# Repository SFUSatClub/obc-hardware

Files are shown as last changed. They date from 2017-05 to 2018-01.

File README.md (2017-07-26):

# OBC Hardware #

**demoboard_v1:** test board featuring RTC, flash memory, watchdog and SEL protection, to be tested with the TMS570LS0432 Launchpad board.

**OBC_prototypeA:** design for PC104 compliant OBC prototype, including onboard MCU, flash memory, SEL protection and power supplies. Includes all features of demoboard, interfaced to TMS570LS0714 MCU.

**Kicad-Lib:** SFUSat's common footprint and schematic symbol library.

## Getting started: ##
Clone this repo In the obc-hardware directory, run git submodule init In the obc-hardware directory, run git submodule update

Open KiCAD, navigate to the project you're interested in.
In EESchema, go to Preferences > Component Libraries
1. "Add" a user defined search path, select the KiCad-Lib directory in the obc-hardware directory
2. "Add" component library files and select the SFUSat.lib file in the KiCad-Lib folder
3. Press ok.

**Note:** issues may arise when using relative paths. Select absolute paths by choosing "No" when asked if you want to use a relative path

Exit back to the KiCad home window and go to Pcbnew > Preferences > Footprint Libraries Manager > "Project Specific Libraies" tab:

1. "Add Library"
2. Nickname: SFUSat
3. Library Path: ${KIPRJMOD}/KiCad-Lib/SFUSat.pretty

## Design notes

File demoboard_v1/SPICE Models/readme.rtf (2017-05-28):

The SPICE model for the DMN2075U needs to be included as a sub circuit. For copyright reasons, it is not posted to git, but can be downloaded from here:

https://www.diodes.com/products/discrete/mosfets/mosfet-master-table/part/DMN2075U

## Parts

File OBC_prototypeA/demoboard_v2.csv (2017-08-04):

Reference | Value | Footprint | Datasheet
U2 | AP7331 | SFUSat:SOT25
P1 | 3v3_IN_CONNECTOR | SFUSat:2x01In_Header_v2
C2 | 1uF | SFUSat:C_0402
C21 | 1µF | SFUSat:C_0402
U1 | TMS570LS0714 | Housings_QFP:LQFP-144_20x20mm_Pitch0.5mm
C17 | 0.1µF | SFUSat:C_0402
C19 | 0.1µF | SFUSat:C_0402
C20 | 0.1µF | SFUSat:C_0402
C14 | 0.1µF | SFUSat:C_0402
C15 | 0.1µF | SFUSat:C_0402
C16 | 0.1µF | SFUSat:C_0402
C18 | 0.1µF | SFUSat:C_0402
C4 | 0.1µF | SFUSat:C_0402
C5 | 0.1µF | SFUSat:C_0402
C6 | 0.1µF | SFUSat:C_0402
C7 | 0.1µF | SFUSat:C_0402
C9 | 0.1µF | SFUSat:C_0402
C10 | 0.1µF | SFUSat:C_0402
C11 | 0.1µF | SFUSat:C_0402
C12 | 0.1µF | SFUSat:C_0402
C13 | 0.1µF | SFUSat:C_0402
U3 | AP7361_3.3v | SFUSat:SOT-223
C23 | 1µF | SFUSat:C_0402
C22 | 4.7µF | SFUSat:C_0402
U4 | INA301 | SFUSat:VSSOP_8
R1 | 7.5k | SFUSat:R_0402
R3 | 0.04 | Resistors_SMD:R_2512
P2 | INA_INPUT | SFUSat:3x_01In_Header_v2
P3 | INA_GND | SFUSat:3x_01In_Header_v2
P4 | INA_EN | SFUSat:2x01In_Header_v2
Q1 | DMN2075U | SFUSat:SOT23_DMN2075U
R4 | 10k | SFUSat:R_0402
P5 | INA_OUTPUT | SFUSat:2x01In_Header_v2
Q2 | DMN2075U | SFUSat:SOT23_DMN2075U
Q3 | 1v2_GOOD | SFUSat:SOT23_DMN2075U
D1 | LED | SFUSat:LED_0603
R6 | 270 | SFUSat:R_0402
R5 | 10K | SFUSat:R_0402
VR1 | Trimpot | SFUSat:Trimpot_Bourns_TC33
J1 | PC104-8BIT | SFUSat:PC104-8bit
Q4 | DMN2075U | SFUSat:SOT23_DMN2075U
D2 | PESD5Zx | SFUSat:PESD57zx
P6 | USB_PORT | SFUSat:USB_MINIB_SMD
U10 | FT230XQ-R | SFUSat:QFN-16_650P
P11 | USB_5V | SFUSat:2x01In_Header_v2
R2 | 27 | SFUSat:R_0402
R31 | 27 | SFUSat:R_0402
C33 | 10nF | SFUSat:C_0402
C8 | 100nF | SFUSat:C_0402
R32 | 10k | SFUSat:R_0402
R33 | 10k | SFUSat:R_0402
R34 | 10k | SFUSat:R_0402
R35 | 10k | SFUSat:R_0402
R36 | 270 | SFUSat:R_0402
R37 | 270 | SFUSat:R_0402
D4 | TX | SFUSat:LED_0603
D5 | RX | SFUSat:LED_0603
W15 | TEST_1P | SFUSat:Test_Point
Y1 | XTAL | SFUSat:SMD_XTAL
C27 | 33pF | SFUSat:C_0402
C28 | 33pF | SFUSat:C_0402
P7 | OSC_FUALT_INJECT | SFUSat:2x01In_Header_v2
SW2 | SPST | SFUSat:Tact_SW_SMD_v2
W12 | nERROR | SFUSat:Test_Point
C32 | 0.1µF | SFUSat:C_0402
R25 | 10k | SFUSat:R_0402
U9 | TPS3110 | SFUSat:SOT_23_6
C31 | 0.1µF | SFUSat:C_0402
SW1 | SPST | SFUSat:Tact_SW_SMD_v2
R22 | 200k | SFUSat:R_0402
R23 | 187k | SFUSat:R_0402
R24 | 100k | SFUSat:R_0402
W14 | RESET_TEST | SFUSat:Test_Point
R28 | 100k | SFUSat:R_0402
R27 | 100k | SFUSat:R_0402
R29 | 100k | SFUSat:R_0402
R30 | 100k | SFUSat:R_0402
P12 | JTAG_20PIN | SFUSat:JTAG_20pin
JTAG5V_IN1 | JTAG5V_IN | SFUSat:2x01In_Header_v2
P13 | WD_EN | SFUSat:2x01In_Header_v2
R38 | 1k | SFUSat:R_0402
R7 | 10k | SFUSat:R_0402
W7 | AD1EVT1 | SFUSat:Test_Point
W8 | GIOB2 | SFUSat:Test_Point
Q5 | DMN2075U | SFUSat:SOT23_DMN2075U
D3 | LED | SFUSat:LED_0603
R9 | 270 | SFUSat:R_0402
R8 | 10k | SFUSat:R_0402
R26 | 10k | SFUSat:R_0402
W13 | WD_TEST | SFUSat:Test_Point
U5 | FLASH_IS25LP016D | SFUSat:SOT-8_208mil_medium
R11 | 10k | SFUSat:R_0402
C24 | 0.1µF | SFUSat:C_0402
R10 | 10k | SFUSat:R_0402
W1 | TEST_1P | SFUSat:Test_Point
R12 | 0 | SFUSat:R_0402
R13 | 10k | SFUSat:R_0402
W2 | TEST_1P | SFUSat:Test_Point
U6 | FLASH_IS25LP016D | SFUSat:SOT-8_208mil_medium
R15 | 10k | SFUSat:R_0402
C25 | 0.1µF | SFUSat:C_0402
R14 | 10k | SFUSat:R_0402
W3 | TEST_1P | SFUSat:Test_Point
R16 | 0 | SFUSat:R_0402
R17 | 10k | SFUSat:R_0402
W4 | TEST_1P | SFUSat:Test_Point
U7 | FLASH_IS25LP016D | SFUSat:SOT-8_208mil_medium
R19 | 10k | SFUSat:R_0402
C26 | 0.1µF | SFUSat:C_0402
R18 | 10k | SFUSat:R_0402
W5 | TEST_1P | SFUSat:Test_Point
R20 | 0 | SFUSat:R_0402
R21 | 10k | SFUSat:R_0402
W6 | TEST_1P | SFUSat:Test_Point
P10 | FLASH_CS | SFUSat:3x_01In_Header_v2
P9 | FLASH_SPI | SFUSat:3x_01In_Header_v2
U8 | AB-RTCMC-EOA9-S3 | SFUSat:RTC_AB-RTCMC_EA09_S3
C29 | 10nF | SFUSat:C_0402
C30 | 470µF | SFUSat:Supercap_v2
W9 | CLKOUT | SFUSat:Test_Point
W11 | RTC_INT | SFUSat:Test_Point
W10 | RTC_OE | SFUSat:Test_Point
P8 | RTC_SPI | SFUSat:4x01In_Header_v2

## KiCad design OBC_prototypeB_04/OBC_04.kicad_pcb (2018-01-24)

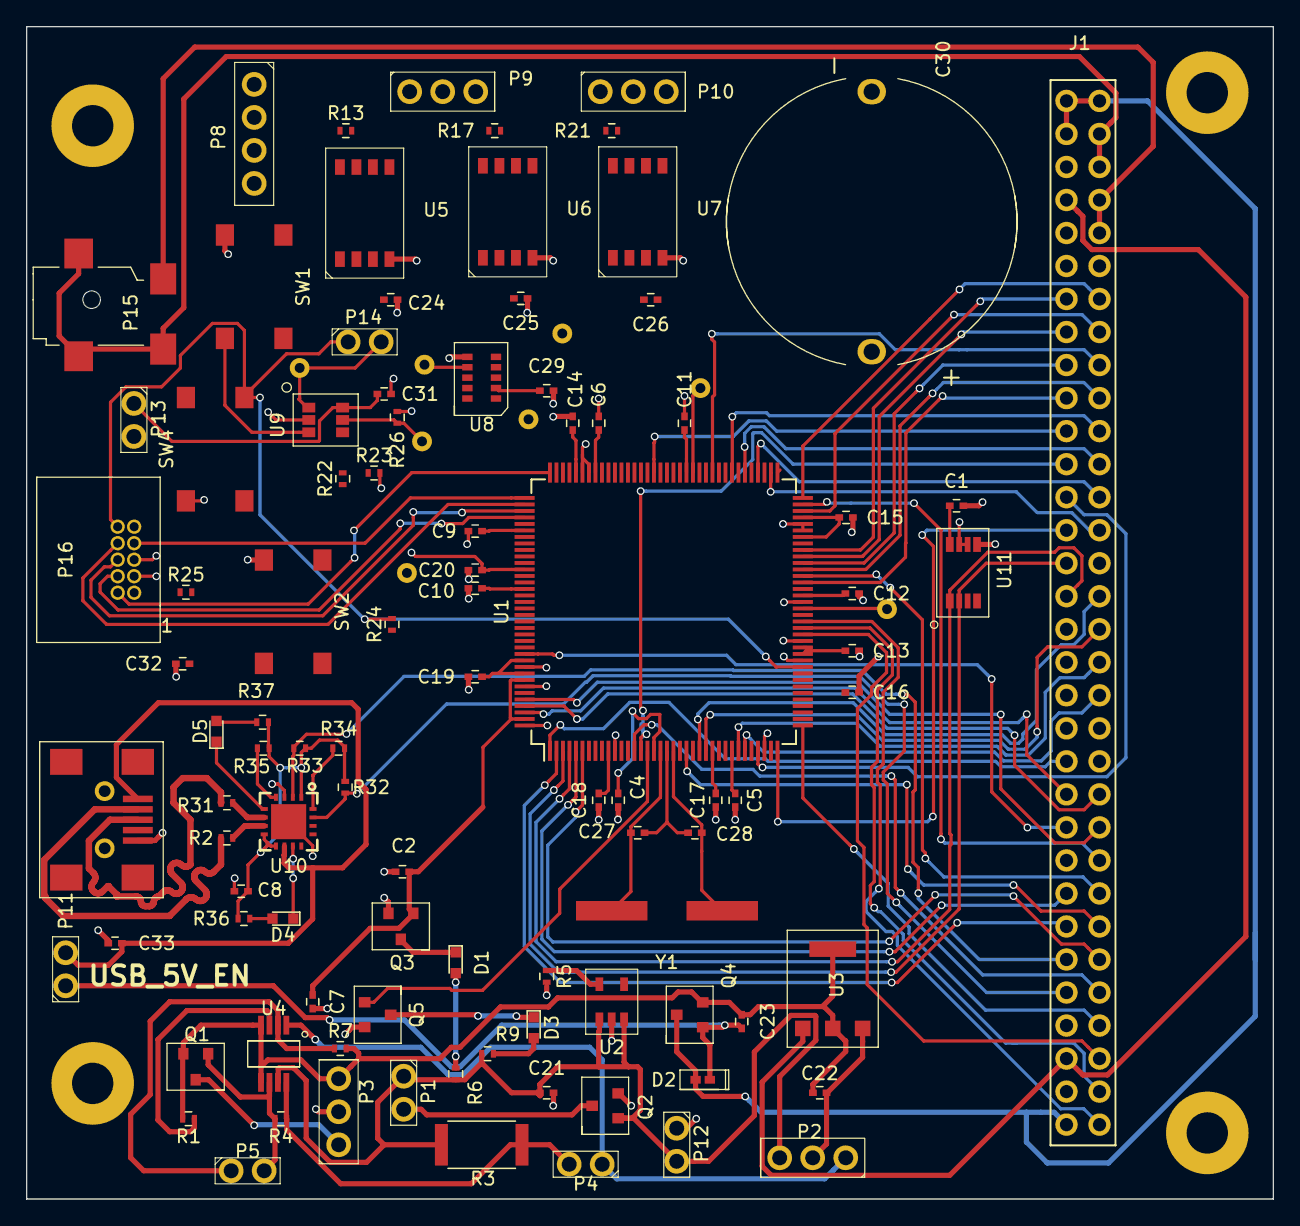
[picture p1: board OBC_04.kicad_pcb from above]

Board: 2 copper layers, 95.9 x 90.2 mm, 104 parts (0 on the bottom side), 107 nets.

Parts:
C1, C4, C5, C6, C7, C9, C10, C11, C12, C13, C14, C15, C16, C17, C18, C19, C20, C24, C25, C26, C31, C32: 0.1µF; C_0402
C2: 10µF; C_0402
C8: 100nF; C_0402
C21, C23: 1µF; C_0402
C22: 4.7µF; C_0402
C27, C28: 33pF; C_0402
C29, C33: 10nF; C_0402
C30: 470µF; Supercap_v2
D1, D3: LED; LED_0603
D2: PESD5Zx; PESD57zx
D4: TX; LED_0603
D5: RX; LED_0603
J1: PC104-8BIT; PC104-8bit
P1: 3v3_IN_CONNECTOR; 2x01In_Header_v2
P2: INA_INPUT; 3x_01In_Header_v2
P3: INA_GND; 3x_01In_Header_v2
P4: INA_EN; 2x01In_Header_v2
P5: INA_OUTPUT; 2x01In_Header_v2
P6: USB_PORT; USB_MINIB_SMD
P8: RTC_SPI; 4x01In_Header_v2
P9: FLASH_SPI; 3x_01In_Header_v2
P10: FLASH_CS; 3x_01In_Header_v2
P11: USB_5V; 2x01In_Header_v2
P12: LOAD; 2x01In_Header_v2
P13: WD_EN; 2x01In_Header_v2
P14: WD_RST_EN; 2x01In_Header_v2
P15: 3pin-DC-power; PJ-028-SMT-TR-3pin-DC-jackPJ-028-SMT-TR
P16: JTAG_10PIN; JTAG_10pin_1.27mm
Q1, Q2, Q4, Q5: DMN2075U; SOT23_DMN2075U
Q3: 1v2_GOOD; SOT23_DMN2075U
R1: 7.5k; R_0402
R2, R31: 27; R_0402
R3: 0.04; R_2512
R4, R7, R13, R17, R21, R25, R26, R32, R33, R34, R35: 10k; R_0402
R5: 10K; R_0402
R6, R9, R36, R37: 270; R_0402
R22: 200k; R_0402
R23: 187k; R_0402
R24: 2.2k; R_0402
SW1, SW2, SW4: SPST; Tact_SW_SMD_v2
U1: TMS570LS0714; LQFP-144_20x20mm_Pitch0.5mm
U2: XC6222B121MR-G; SOT25
U3: AP7361_3.3v; SOT-223
U4: INA301; VSSOP_8
U5, U6, U7: FLASH_IS25LP016D; SOT-8_208mil_medium
U8: AB-RTCMC-EOA9-S3; RTC_AB-RTCMC_EA09_S3
U9: TPS3110; SOT_23_6
U10: FT230XQ-R; QFN-16_650P
U11: STLM75; TSSOP-8-3x3mm-SOT505-1
W7: AD1EVT1; Test_Point
W8: GIOB2; Test_Point
W9: CLKOUT; Test_Point
W10: RTC_OE; Test_Point
W11: RTC_INT; Test_Point
W12: nERROR; Test_Point
W13: WD_TEST; Test_Point
W14: RESET_TEST; Test_Point
Y1: XTAL; SMD_XTAL

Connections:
1v2: C2.1, C4.1, C5.1, C6.1, C7.1, C9.1, C10.1, C11.1, C12.1, C13.1, Q3.2, R5.1, R22.1, U1.17, U1.29, U1.45, U1.48, U1.49, U1.57, U1.87, U1.101, U1.114, U1.123, U1.137, U1.143, U2.5
3v3: C1.1, C14.2, C15.1, C16.1, C17.2, C18.1, C19.1, C20.1, C21.1, C24.2, C25.2, C26.2, C29.1, P1.1, P2.3, P12.2, P13.2, P16.1, Q2.2, R3.2, R6.1, R9.1, R13.1, R17.1, R21.1, R24.1, R25.1, U1.10, U1.26, U1.42, U1.66, U1.69, U1.104, U1.120, U1.134, U1.136, U2.1, U2.3, U4.7, U5.3, U5.8, U6.3, U6.8, U7.3, U7.8, U8.2, U11.8
3v3_OUTPUT: C22.1, P2.2, U3.3
5v0: C23.1, D2.1, J1.3B, J1.29B, P11.1, Q4.2, U3.1
104_GND: C22.2, C23.2, P3.3, Q1.3, Q4.3, R1.2, R7.2, U3.2, U3.4, U4.4, U4.5
104_In_GND: C8.2, C33.2, D2.2, J1.1B, J1.31B, J1.32A, J1.32B, P6.5, Q4.1, U10.3, U10.13, U10.17
/MCU_Support_Reset/OSC_N: C28.2, U1.20, Y1.2
/MCU_Support_Reset/OSC_P: C27.1, U1.18, Y1.1
/PC104_Connector/RUSB_N: R2.1, U10.7
/PC104_Connector/RUSB_P: R31.1, U10.6
AD1_3: J1.19A, U1.74
AD1_4: J1.20A, U1.76
AD1_5: J1.21A, U1.78
AD1_6: J1.22A, U1.80
AD1_7: J1.23A, U1.61
AD1_8: J1.24A, U1.83
AD1_9: J1.25A, U1.70
AD1_10: J1.26A, U1.72
AD1_17: J1.23B, U1.59
AD1_18: J1.24B, U1.62
AD1_19: J1.25B, U1.63
AD1_20: J1.26B, U1.64
ANTENNA_DEPLOY: J1.7A, U1.22
FLASH0_CS: P10.3, U1.105, U5.1
FLASH1_CS: P10.2, U1.130, U6.1
FLASH2_CS: P10.1, U1.40, U7.1
FLASH_CLK: P9.1, U1.95, U5.6, U6.6, U7.6
FLASH_MISO: P9.2, U1.94, U5.2, U6.2, U7.2
FLASH_MOSI: P9.3, U1.93, U5.5, U6.5, U7.5
FTDI_VCCIO: C8.1, R32.1, R33.1, R34.1, R35.1, R36.1, R37.1, U10.1, U10.8, U10.9
GIOA0: J1.7B, U1.2
GIOA1: J1.8B, U1.5
GIOA6: Q5.2, U1.16
GIOB1: J1.10B, U1.133, U8.7, W11.1
GIOB2: J1.11B, U1.142
GIOB3: J1.12B, U1.1
GND: C1.2, C2.2, C4.2, C5.2, C6.2, C7.2, C9.2, C10.2, C11.2, C12.2, C13.2, C14.1, C15.2, C16.2, C17.1, C18.2, C19.2, C20.2, C21.2, C24.1, C25.1, C26.1, C29.2, C30.2, C31.2, C32.2, P3.2, P12.1, P16.3, P16.5, Q2.3, Q3.3, Q5.3, R5.2, R23.2, R26.2, SW1.2, SW2.2, SW4.2, U1.11, U1.21, U1.27, U1.28, U1.34, U1.43, U1.44, U1.47, U1.50, U1.56, U1.67, U1.68, U1.88, U1.102, U1.103, U1.115, U1.121, U1.122, U1.135, U1.138, U1.144, U2.2, U5.4, U6.4, U7.4, U8.6, U9.2, U11.4, U11.5, U11.6, U11.7
I2C_SCL: J1.18B, U1.3, U11.2
I2C_SDA: J1.17B, U1.4, U11.1
INA_ALERT: P5.2, Q1.2, R4.2, U4.6
INA_INPUT: P2.1, P4.1, U4.1
INA_OUT: P5.1, R7.1, U1.73, U4.2
MASTER_RESET: P14.1, P16.10, R24.2, SW4.1, U1.46
NHET1_4: J1.19B, U1.36
NHET1_7: J1.20B, U1.33
NHET1_22: J1.21B, U1.15
NHET1_26: J1.22B, U1.92
unnamed: C27.2, C28.1, U1.19
unnamed: C30.1, U8.9
unnamed: C31.1, P13.1, U9.6
unnamed: C32.1, R25.2, SW2.1, U1.116
unnamed: D1.1, Q3.1
unnamed: D1.2, R6.2
unnamed: D3.1, Q5.1
unnamed: D3.2, R9.2
unnamed: D4.1, U10.11
unnamed: D4.2, R36.2
unnamed: D5.1, U10.5
unnamed: D5.2, R37.2
unnamed: J1.28A, J1.29A, P15.1
unnamed: J1.30A, J1.31A, P15.2, P15.3
unnamed: P1.2, Q2.1
unnamed: P3.1, Q1.1
unnamed: P4.2, R3.1, R4.1, U4.8
unnamed: P14.2, U9.1, W14.1
unnamed: R1.1, U4.3
unnamed: R13.2, U5.7
unnamed: R17.2, U6.7
unnamed: R21.2, U7.7
unnamed: R22.2, R23.1, U9.4
unnamed: R34.2, U10.16
unnamed: R35.2, U10.4
unnamed: SW1.1, U9.3
unnamed: U1.55, W8.1
unnamed: U1.86, W7.1
unnamed: U8.1, W10.1
unnamed: U8.3, W9.1
RF_ADC1: J1.8A, U1.60
RF_ADC2: J1.9A, U1.71
RF_CLK: J1.1A, U1.53
RF_CS: J1.4A, U1.37
RF_GAIN_CS: J1.6A, U1.6
RF_IRQ: J1.5A, U1.14
RF_MISO: J1.3A, U1.51
RF_MOSI: J1.2A, U1.52
RF_PWM1: J1.10A, U1.140
RF_PWM2: J1.11A, U1.141
RTC_CLK: P8.2, U1.100, U8.4
RTC_CS: P8.1, U1.32, U8.8
RTC_MISO: P8.3, U1.98, U8.5
RTC_MOSI: P8.4, U1.99, U8.10
SPI4_CLK: J1.16A, U1.25
SPI4_CS0: J1.17A, U1.24
SPI4_MISO: J1.14A, U1.31
SPI4_MOSI: J1.15A, U1.30
TCK: P16.4, U1.112
TDI: P16.8, U1.110
TDO: P16.6, U1.111
TMS: P16.2, U1.108
UART_RX: J1.5B, R32.2, U1.38, U10.15
UART_TX: J1.6B, R33.2, U1.39, U10.2
USB_5V: C33.1, P6.1, P11.2, U10.10
USB_N: P6.2, R2.2
USB_P: P6.3, R31.2
WATCHDOG: R26.1, U1.126, U9.5, W13.1
nERROR: U1.117, W12.1
nTRST: P16.7, U1.109

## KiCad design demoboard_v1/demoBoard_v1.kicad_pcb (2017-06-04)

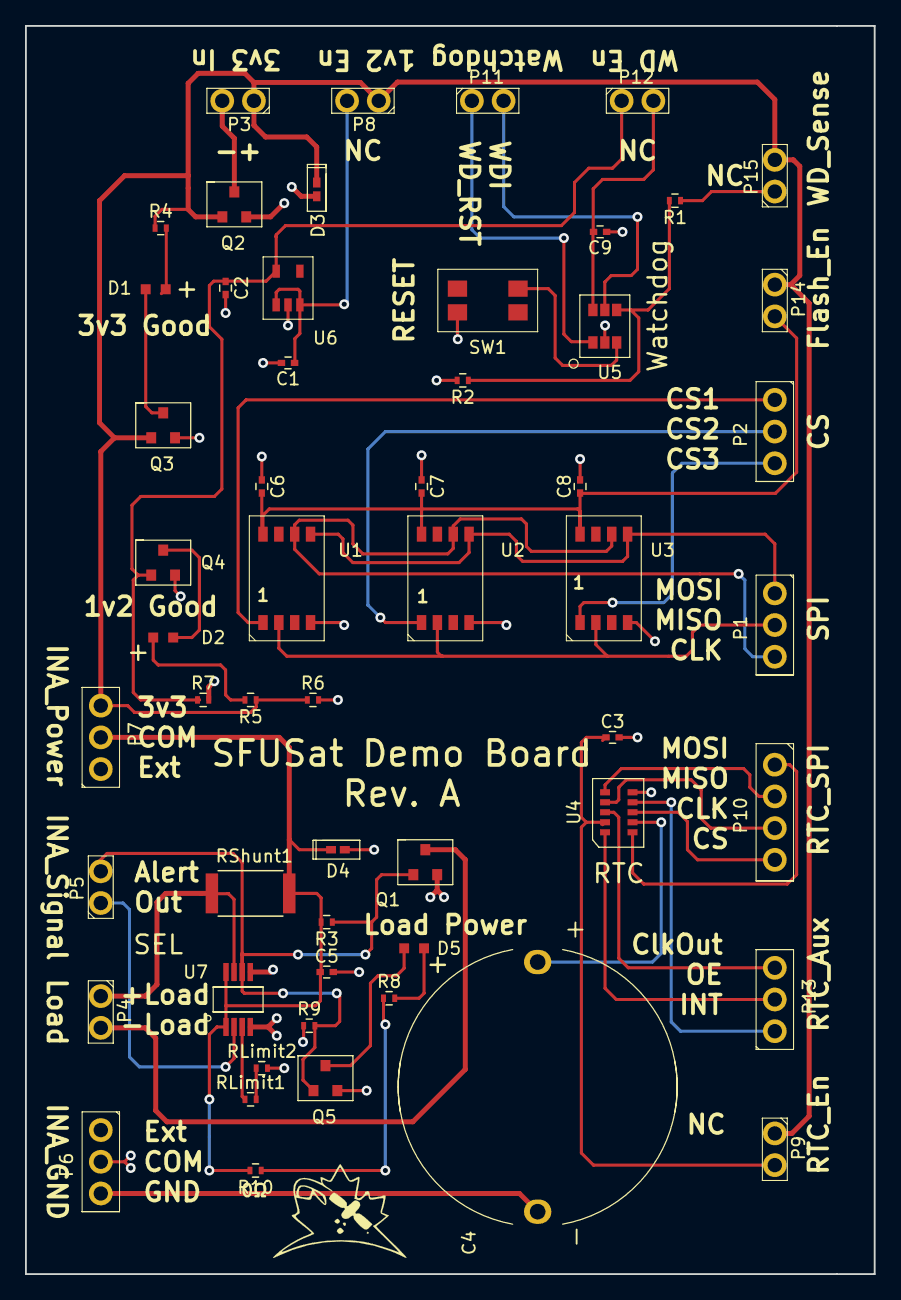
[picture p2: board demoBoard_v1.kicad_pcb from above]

Board: 2 copper layers, 68.0 x 100.0 mm, 55 parts (0 on the bottom side), 42 nets.

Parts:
C1, C2: 1µF; C_0402
C3: 10nF; C_0402
C4: 470µF; Supercap_v2
C5, C6, C7, C8, C9: 0.1µF; C_0402
D1: 3.3V On; LED_150060GS75000
D2: 1.2V On; LED_150060GS75000
D3, D4: PESD5Zx; PESD57zx
D5: Led_Small; LED_150060GS75000
P1: SPI_Header; 3x_01In_Header_v2
P2: 3x_CS_Header; 3x_01In_Header_v2
P3: Power_Header; 2x01In_Header_v2
P4: LOAD; 2x01In_Header_v2
P5: INA_Signal; 2x01In_Header_v2
P6: INA_GND; 3x_01In_Header_v2
P7: INA_Power; 3x_01In_Header_v2
P8: 1.2V_3.3V_NC; 2x01In_Header_v2
P9: RTC_3.3_NC; 2x01In_Header_v2
P10: RTC_Serial; 4x01In_Header_v2
P11: WD_Header; 2x01In_Header_v2
P12: WD_1.2V_NC; 2x01In_Header_v2
P13: RTC_Aux; 3x_01In_Header_v2
P14: Flash_3v3_NC; 2x01In_Header_v2
P15: WD_SENSE_3.3V_NC; 2x01In_Header_v2
Q1, Q2, Q3, Q4, Q5: DMN2075U; SOT23_DMN2075U
R1: 820K; R_0402
R2: 180K; R_0402
R3, R6, R7: 10K; R_0402
R4, R5, R8: 39; R_0402
R9: 10k; R_0402
R10: 0; R_0402
RLimit1: 8870; R_0402
RLimit2: 130; R_0402
RShunt1: 0.06; R_2512
SW1: Tact_Switch_NO; Tact_SW_SMD
U1, U2, U3: S25FL164K0XMFV010; SOT-8_208mil_medium
U4: AB-RTCMC-EOA9-S3; RTC_AB-RTCMC_EA09_S3
U5: TPS3110; SOT_23_6
U6: AP7331; SOT25
U7: INA301; VSSOP_8

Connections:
+1V2: C2.1, P12.1, Q4.2, R7.1, U6.5
+3V3: D3.1, P3.1, P7.3, P8.1, P9.1, P14.1, P15.2, Q2.2, Q3.2, R4.1, R5.1, R6.1
CLKOut: P13.3, U4.3
CS_1: P2.1, U1.1
CS_2: P2.2, U2.1
CS_3: P2.3, U3.1
Flash_MISO: P1.2, U1.2, U2.2, U3.2
Flash_MOSI: P1.1, U1.5, U2.5, U3.5
Flash_SCK: P1.3, U1.6, U2.6, U3.6
GND: C1.2, C2.2, C3.2, C4.2, C6.1, C7.1, C8.2, C9.1, D3.2, P6.3, Q2.3, Q3.3, Q4.3, R2.2, R6.2, R7.2, SW1.3, U1.4, U2.4, U3.4, U4.6, U5.2, U6.2
Header_GND: P3.2, Q2.1
INA_Alert: P5.2, Q1.2, Q5.2, R3.1, R9.2, U7.6
INA_GND: C5.2, D4.2, P6.2, Q1.3, Q5.3, R9.1, RLimit2.2, U7.4, U7.5
INA_Out: P5.1, U7.2
INA_Supply: C5.1, D4.1, P7.2, R3.2, R10.2, RShunt1.1, U7.1, U7.8
Load+: P4.1, RShunt1.2, U7.7
Load-: P4.2, Q1.1
unnamed: C1.1, P8.2, U6.1, U6.3
unnamed: C3.1, P9.2, U4.2
unnamed: C4.1, U4.9
unnamed: C6.2, C7.2, C8.1, P14.2, U1.8, U2.8, U3.8
unnamed: C9.2, P12.2, U5.6
unnamed: D1.1, Q3.1
unnamed: D1.2, R4.2
unnamed: D2.1, Q4.1
unnamed: D2.2, R5.2
unnamed: D5.1, Q5.1
unnamed: D5.2, R8.2
unnamed: P15.1, R1.1
unnamed: R1.2, R2.1, U5.4
unnamed: R8.1, R10.1
unnamed: RLimit1.1, U7.3
unnamed: RLimit1.2, RLimit2.1
unnamed: SW1.2, U5.3
RTC_CS: P10.4, U4.8
RTC_INT: P13.1, U4.7
RTC_MISO: P10.2, U4.5
RTC_MOSI: P10.1, U4.10
RTC_OE: P13.2, U4.1
RTC_SCL: P10.3, U4.4
WDI: P11.2, U5.5
WD_RESET: P11.1, U5.1

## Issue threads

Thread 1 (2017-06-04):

Update RTC Footprint

richarthurs, 2017-06-04:
The datasheet for the RTC uses a 1st angle projection, and thus shows the footprint as a bottom view instead of a top view. Footprint needs to be flipped along the horizontal axis. Trust the picture/rendering, not the drawing. Pin 1 has the cut-off corner.

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

Closed 2017-06-30.

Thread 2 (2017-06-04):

Adjust footprint of capacitors

liquiddandruff, 2017-06-04:
From yesterday's assembly, the distance between each pad for the capacitors we used seems a bit too far; perhaps could be adjusted slightly (closer) for future revision.

richarthurs, 2017-06-04:
Original pad spacing was 0.25mm (pad edge-centerline). Data sheet says 0.3mm which is crazy. Changed to 0.225mm.

http://search.murata.co.jp/Ceramy/image/img/A01X/G101/ENG/GRM155R71H103KA88-01.pdf

Closed 2017-06-04.

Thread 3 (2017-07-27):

Add jumper to USB 5V0 line

Alenux55, 2017-07-27:
Currently USB 5V0 line is connected directly to PC-104 connector 5V0 pin, which would contend with the 5V0 coming from the power board.

Add a connector (something like a [0.1" two-pin header](https://www.digikey.ca/products/en?keywords=S1011EC-02-ND)) so the USB power can be disabled.

richarthurs, 2017-07-31:
fixed in e8887260e9f13a514a2e4212145bce58cf511cf9

Closed 2017-07-31.

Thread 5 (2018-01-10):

i2c analog switch (or SPI)

richarthurs, 2018-01-10:
these will connect up to the sun sensors

richarthurs, 2018-01-10:
http://www.analog.com/en/products/switches-multiplexers/analog-switches-multiplexers/adg728.html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

i2c controlled 8:1 analog switch

Closed 2018-02-13.

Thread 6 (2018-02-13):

New 1.2 volt regulator

richarthurs, 2018-02-13:
The current 1.2 V regulator is a very small package and gets quite hot. Replace with a larger, more efficient part.

Current capacity: 500 mA
1.2 V from 3.3
Linear

richarthurs, 2018-03-17:
Selected:

MCP1825S-1202E/DB

Has nice thermal limits, auto thermal shutdown, larger package that shouldn't get as hot.

Closed 2018-03-17.

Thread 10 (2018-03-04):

All of the GPIO

richarthurs, 2018-03-04:
Connect any unused SPI/MIBSPI pin to the 104 connector. We will configure them as GPIOs to deal with things like the deployment switches.

Relevant documents:
https://docs.google.com/spreadsheets/d/18xcmCFIcJfGPVsIEUiorDKSEqSlVrN3KZPtd_hJD58o/edit#gid=370382017

https://docs.google.com/spreadsheets/d/1k9-GxSDjCNQlImQ5CRE3hHjOckTxFv60mS3J6f4K6jU/edit#gid=677351093

richarthurs, 2018-03-18:
Added 4 spare GPIO to CAN pins

Closed 2018-03-18.

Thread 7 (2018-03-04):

RTC SPI Labels are Wrong

richarthurs, 2018-03-04:
Connections are ok but the labels are wrong

richarthurs, 2018-03-17:
Fixed in 0.5

Closed 2018-03-17.

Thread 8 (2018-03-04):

PC104 Connector Placed Incorrectly

richarthurs, 2018-03-04:
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

Needs to be moved left a few mm

richarthurs, 2018-03-17:
Fixed in a742e3b441656224ec3b36e43ef81ebca874f4db

Closed 2018-03-17.

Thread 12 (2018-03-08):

3.3V, 5V on 0.5

richarthurs, 2018-03-08:
We receive board level 3.3v in over the 104 connector.

Let's have our own 3.3V connector so we can power without touching 104 (directly connected to 104 connector 3v3 pins)

Closed 2018-03-19.

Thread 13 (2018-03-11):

New Flash

richarthurs, 2018-03-11:
Somehow I screwed up the memory model and it turns out we need 8 MB of flash (64 mbit) to have a good margin, not 2MB.

Something like this would be a drop-in replacement: https://www.digikey.ca/product-detail/en/issi-integrated-silicon-solution-inc/IS25LP064A-JBLE/706-1440-5-ND/5431598

richarthurs, 2018-03-17:
Added to BOM. Since it's a drop in replacement, we'll just buy a few and populate where required.

Closed 2018-03-17.

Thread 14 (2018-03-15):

Grounding Issue with INA?

richarthurs, 2018-03-15:
With the following jumpers connected:

- INA_EN
- GND + ON
- COM + INA_IN

the external UART is wonky. If you ground the external UART to the 104 connector, it shorts? If you ground it to the GND jumper, nothing changes.

With the two power jumpers connected as mentioned above but INA_EN open, everything is ok.

- Determine if it's resetting or something.

richarthurs, 2018-03-19:
Nope, turned out to be a config issue where the reverse polarity FET gate was not being driven, causing ground to disconnect.

On 0.4:
- 3v3 to INA_IN, GND to 104 gnd pin. Must jump 3v3 pin (on the INA source control header) and 5V on the 104 connector to turn on the 5V reverse polarity FET and have a full loop.

- or power through the 5V in on the 104 connector

Closed 2018-03-19.

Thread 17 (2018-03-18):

INA config through 0Ω resistors

richarthurs, 2018-03-18:
Currently using headers, move to resistors which will be more reliable in a flight configuration

0603 resistors

richarthurs, 2018-03-19:
Actually we'll use headers and solder jumpers for flight. Much easier to debug

Closed 2018-03-19.

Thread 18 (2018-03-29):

Assembly notes

richarthurs, 2018-03-29:
- DNP other flash chips
- GPS config resistors: expected configuration is even #’s populated with 0Ω
- Capacitors C37-C40 were not present on v0.3, but were added to 0.5 to improve reliability

Replicated in the changelog doc https://docs.google.com/document/d/1P-e3Ej1pEhi8Bjl_-oQ73YgwDQVOz6J4nHh6tHJnMpo/edit

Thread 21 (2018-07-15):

USB Current Limiting

richarthurs, 2018-07-15:
Generally, plugging the bare OBC into any laptop or USB hub will work.

It was observed that an OBC + radio would cause issues (only tested on Richard's MBP), and would frequently draw too much current and cause the OS to shut down the USB port.

The combined draw of OBC + RF is still likely under 500 mA, so the culprit is likely this clause of the USB spec:

> iii) A bus powered high power USB device (one that draws more than 100mA) should use one of the
CBUS pins configured as PWREN# and use it to keep the current below 100mA on plug-in and
2.5mA on USB suspend.

Since the OBC and radio were connected at plug-in, the current drawn would be over 100 mA.

### Fix
One fix for this would be to have one of the PWREN pins tied to MCU reset, so the OBC would be drawing very little current at plug-in.

If future stack designs have the ability for the OBC to entirely disable subsystems, the OBC should talk to the FTDI and only enable the subsystems some time after plug in.

It may also be possible to do some other current limiting.

http://www.ftdichip.com/Support/Documents/DataSheets/ICs/DS_FT230X.pdf

richarthurs, 2018-07-18:
Might something like this be useful? https://www.digikey.ca/product-detail/en/maxim-integrated/MAX22505GTG-/MAX22505GTG--ND/8635404

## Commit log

2017-05-11 added memory interfce and started watchdog
    [demoBoard_v1.kicad_pcb, demoBoard_v1.sch]
2017-05-19 Nearly done, todo: fix current shunt, add LEDs, add footprints and make PCB
    [demoBoard_v1.sch]
2017-05-22 Todo: change MOSFET and add indicator LEDs
    [demoBoard_v1.sch]
2017-05-22 Updated FET, added indicator LEDs on 3.3v and 1.2v rails.
    [demoBoard_v1.sch]
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2017-05-22 Finished initial PCB layout
    [_saved_demoBoard_v1.sch, demoBoard_v1.kicad_pcb, demoBoard_v1.sch]
2017-05-23 Starting to redo things after this commit.
    [demoBoard_v1.kicad_pcb]
2017-05-23 Cleaned up and made the board smaller. Began adding silkscreen
    [demoBoard_v1.kicad_pcb]
2017-05-24 Added separate ground pane for SEL monitor to facilitate independent testing of it. Beefed up power tracks. Discovered error with external load connection being shorted to ground at the connector, an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
    [demoBoard_v1.kicad_pcb]
2017-05-24 Fixed SEL monitor mistake ground connection
    [demoBoard_v1.kicad_pcb, demoBoard_v1.sch]
2017-05-24 Added more silkscreens including the logo. Reorganized some traces
    [demoBoard_v1.kicad_pcb]
2017-05-24 Added TVS and INA indicator LED to schematic. Committing before adding footprint and PCB traces.
    [demoBoard_v1.sch]
2017-05-24 Ready to be sent to board house
    [demoBoard_v1.kicad_pcb, demoBoard_v1.sch]
2017-05-24 Ready to be sent to board house. Last minute changed via size to be safe.
    [demoBoard_v1.kicad_pcb]
2017-05-24 moved some vias to avoid a silkscreen
    [demoBoard_v1.kicad_pcb]
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2017-05-25 Updated LED resistors to 30 ohm, turned RLimit1 into RLimit1 and RLimit2 which are values you can actually buy. Made pin header holes slightly bigger, regenerated gerbers
    [demoBoard_v1-B.Cu.gbr, demoBoard_v1-B.Mask.gbr, demoBoard_v1-B.Paste.gbr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]
2017-05-25 Updated footprints for headers in schematic
    [demoBoard_v1.kicad_pcb, demoBoard_v1.sch]
2017-05-25 Updated pad clearance to 0.075mm, regenerated gerbers
    [demoBoard_v1-B.Cu.gbr, demoBoard_v1-B.Mask.gbr, demoBoard_v1-B.SilkS.gbr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]
2017-05-28 Updated footprint lib with solder paste apertures
    [demoBoard_v1-B.Cu.gbr, demoBoard_v1-B.Mask.gbr, demoBoard_v1-B.SilkS.gbr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]
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2017-06-04 Updated DMN2075 MOSFET symbol
    [demoBoard_v1.sch]
2017-06-04 Updated 0402 capacitor in library. Haven't updated footprints on PCB, although they could be changed.
    [demoBoard_v1.sch]
2017-06-04 Decided to update 0402 resistors and caps to good SFUSat footprints.
    [demoBoard_v1.kicad_pcb]
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2017-06-23 Started new project for board v2, updated footprint for RTC, added all pins of TMS570LS0432
    [1v2_section.sch, bulk_power.sch, demoboard_v2.kicad_pcb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]
2017-06-30 Added 104 connector, put 104 footprint in PCB and have decoupling caps for the mcu.
    [PC104_Connector.sch, bulk_power.sch, demoboard_v2.kicad_pcb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]
2017-06-30 Added RF SPI to schematic
    [PC104_Connector.sch, SPI.sch, bulk_power.sch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]
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2017-07-04 Beginning to add latchup circuit. Latchup protection can be disabled with jumpers, and now has a current limit of 800mA
    [0714spreadsheet.xlsx, MCU_Support_Reset.sch, PC104_Connector.sch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]
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2017-07-07 3v3 reverse polarity FET, connected current monitor to ADC, defined RF PWM and ADC pins on 104 connector, added UART connector, pc104 reverse polarity FET, 104 connector TVS diode.
    [0714spreadsheet.xlsx, ADC.sch, MCU_Support_Reset.sch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]
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2017-07-13 Finished flash memory schematic, added pin 16 LED and 1v2 good LED
    [ADC.sch, Flash.sch, GPIO.sch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]
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2017-07-20 Finished watchdog circuit. Todo: add footprint for tact switch, i2c, UART, USB connector
    [0714spreadsheet.xlsx, ADC.sch, Flash.sch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]
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2017-07-21 Checked design rules, placed decoupling for MCU. Beginning placement
    [bulk_power.sch, demoboard_v2.kicad_pcb]
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2017-07-23 Board layout nearly done - need to add USB jack
    [bulk_power.sch, demoboard_v2.kicad_pcb]
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2017-07-25 I think I fixed the mess with the Kicad-Lib submodule
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2017-07-25 Cleaned up directory structure, added details to readme
    [0714spreadsheet.xlsx, 1v2_section.sch, ADC.sch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]
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2017-07-26 Adjusted solder paste clearance and generated gerbers
    [demoboard_v2-B.Cu.gbr, demoboard_v2-B.Mask.gbr, demoboard_v2-B.SilkS.gbr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]
2017-07-27 Moved outer trace closer in (top left) and updated gitignore
    [demoboard_v2.kicad_pcb]
2017-07-30 Fixing issues raised by board review.
    Orient silkscreen in single direction - done as much as possible.
    Decrease thickness of large font - done.
    Fixed global mask clearance and updated clearence for problematic parts.
    1v2 power net width - 0.25mm can handle 460mA @ 10ºC raise. Max expected is around 360mA (for very brief periods of self test), normal ops are ~150mA.
    Ground island pin 44 of TMS570 - this was always connected, but traces have been re routed to maximize ground plane area.
    Island net U5 - cleaned up the area.
    add gitignore for -bak. Done.
    Todo: add pot for INA301, add FTDI.
    [MCU_Support_Reset.sch, SPI.sch, demoboard_v2.kicad_pcb]
2017-07-30 see previous commit message. Had to add again
    [demoboard_v2.kicad_pcb]
2017-07-30 Added 10k pot and removed R2 to allow current limit to be adjusted
    [ADC.sch, Flash.sch, GPIO.sch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]
2017-07-31 Added FTDI FT230 and beefed up main 1v2 bus lines
    [ADC.sch, Flash.sch, GPIO.sch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]
2017-07-31 Added gerbers, fixed silkscreen width of USB jumper label
    [demoboard_v2-B.Cu.gbr, demoboard_v2-B.Mask.gbr, demoboard_v2-B.SilkS.gbr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]
2017-07-31 Added gerbers, redid USB section (just need to add differential pair), fixed USB connector paste
    [PC104_Connector.sch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]
2017-07-31 Length mached USB traces and cleaned up FTDI region
    [demoboard_v2.kicad_pcb]
2017-07-31 Fixed oscillator circuit.
    [ADC.sch, Flash.sch, GPIO.sch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]
2017-07-31 Routed signal traces outside of the vicinity of the oscillator
    [demoboard_v2.kicad_pcb]
2017-07-31 Cleaned up oscillator traces
    [demoboard_v2.kicad_pcb]
2017-07-31 Removed gnd plane from under oscillator, added differential oscillator signal. Generated gerbers
    [MCU_Support_Reset.sch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]
2017-08-01 Cleaned up some floating traces and silkscreens. Generated gerbers for board house
    [demoboard_v2-B.Cu.gbr, demoboard_v2-B.Mask.gbr, demoboard_v2-B.Paste.gbr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]
2017-08-01 Fixed a few silkscreens
    [demoboard_v2-B.Cu.gbr, demoboard_v2-B.Mask.gbr, demoboard_v2-B.Paste.gbr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]
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2017-08-04 Changed 1.2V regulator from AP7331 to XC6222B121MR-G because the 7331 current limit is too low. Also changed C2 from 1µF to 10µF to meet requirements for new regulator
    [bulk_power.sch, demoboard_v2.csv]
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2018-01-07 Connected A7 to ANTENNA_DEPLOY
    placed DIP switch
    added labels in 104 connector describing GPIO functtionality
    [ADC.sch, Flash.sch, GPIO.sch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]
2018-01-08 Made GPIO reroutes
    B1: is now RTC alert, also on 104 connector
    A0, A2: labelled as RF_deploy on 104 connector (no routing change)
    A5: RF_IRQ
    A7: ANTENNA_DEPLOY
    [GPIO.sch, MCU_Support_Reset.sch, PC104_Connector.sch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]
2018-01-09 Connecte JTAG reset to master reset
    [MCU_Support_Reset.sch]
2018-01-09 Changed RESET circuitry
    Added jumper to disconnect WD from MASTER_RESET
    Changed SW1 name to "Hard reset via WD"
    Added SW4 - direct connect (not via WD) to MCU. Enables manual hard reset with WD disabled.
    [ADC.sch, Flash.sch, GPIO.sch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]
2018-01-09 Tied up flash WP, removed flash CS pullup
    [Flash.sch]
2018-01-09 Removed option to connect flash WP/RESET to MASTER_RESET
    [Flash.sch]
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2018-01-09 Placed 104 connector
    also upstream updates from kicad lib
    [OBC_04.kicad_pcb]
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2018-01-10 Added labels to all GPIO on 104/chip
    Also added sun sensor ADC to 104 connector
    [GPIO.sch, PC104_Connector.sch]
2018-01-17 Added DC in jack for charging
    Also added labels to ADC and GPIO
    [ADC.sch, Flash.sch, GPIO.sch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]
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2018-01-21 Added load connector, switched RTC to MIBSPI5
    RTC on MIBSPI5 because it operates in the same power domain as pretty much everything else. Can now shut off PD3 (though we'd lose I2C access), and the RTC will be fine since it is on PD1.
    [ADC.sch, Flash.sch, GPIO.sch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]
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2018-01-21 Added note about R25, changed value of R24
    [MCU_Support_Reset.sch]
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2018-01-23 Routed USB, started reset area
    [ADC.sch, Flash.sch, GPIO.sch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]
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2018-01-24 changes from work session - power section mostly done
    [OBC_04.kicad_pcb]
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
